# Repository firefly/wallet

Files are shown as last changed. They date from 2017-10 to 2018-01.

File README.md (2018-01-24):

Firefly Wallet
==============

Weclome to the Firefly DIY Air-gapped Hardware Wallet project.

There are still a few things we are working on, but we wanted to start
getting some files into the hands of eager developers.

Also, if you haven't seen it already, please check out our
[crowdsale](https://ethers.io/#!/app-link/contribute.firefly.city). By contributing
to the project, you get your very own yourNameHere.firefly.eth ENS name on the
Ethereum network and you help fund development of the Firefly.

Folders
-------

### Cases

Currently limited to 3D printable cases, but we would love to have other
creative people out there contribute interesting designs.

A better 3D printable case will be published soon, but for the impatient,
the prototype case is available.

### Diagrams

Images and source files used to build documentation. Currently we have a circuit schematic
and a breadboard layout for prototyping.

### Source

The Arduino sketch and required (modified) libraries.

Future
------

- Better 3D printed case; still being designed, but easier to wire (soonish)
- Printed Circuit Board (PCB) layout for more advanced, but tinier devices (future)

License
-------

MIT and BSD license. Each file includes license information at the top.

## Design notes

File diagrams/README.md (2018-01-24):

Diagrams
========

This folder will eventually get rolled into the documentation.

These files are still very experimental.

**Important:** The nRF24L01+ **MUST** be powered with the 3.3V; the 5V rail **WILL** destroy it.

Schematic
---------

The schematic here is a simple overview of the connections required between
the various components.

This schematic diagram can be opened and modified using [kicad](http://kicad-pcb.org).

Breadboard
----------

The breadboard diagram is useful for quickly prototyping the Firefly wallet and
verify components are working coreectly.

The breadboard diagram can be opened and modified using [Fritzing](http://fritzing.org).

License
-------

All documents in here are licensed under the MIT license and the Creative
Commons CC-BY-4 license; whichever you are more comforatable with.

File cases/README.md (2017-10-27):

Cases
=====

Here is a list of cases.

We welcome any interesting additions; they do not need to be 3D printed; a How-To on
building a Firefly into an Altoids tin or other clever ideas are just as awesome.

Credit Card v0.1
----------------

This is the case used for the prototype in our [demo viedo](https://firefly.city/#demo).

It has several problems, which we are addressing in a new revision:

- No power switch
- Overly complicated routing of wires

If you are impatient, feel free to try it out. Otherwise, we highly recommend you wait
for the next version.

Credit Card v0.2
----------------

The changes we are working on:

- Orienting the Arduino Nano to be vertical to minimize wiring distances
- Adding a power slider/spinner
- Likely stacking the batteries

Coming soon.

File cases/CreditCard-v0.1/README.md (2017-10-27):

Credit Card V0.1
================

This is a very early prototype, and my first time using [SketchUp](http://www.sketchup.com).

This is the version seen in the [demo video](https://firefly.city/#demo).

A newer Credit Card V1 will be out soon:

- Shorter wire distances and easier wire routing
- Power switch

However, for a quick and simple case you can use **today**, so you can work
on the Firefly from a coffee shop, this is what we use.

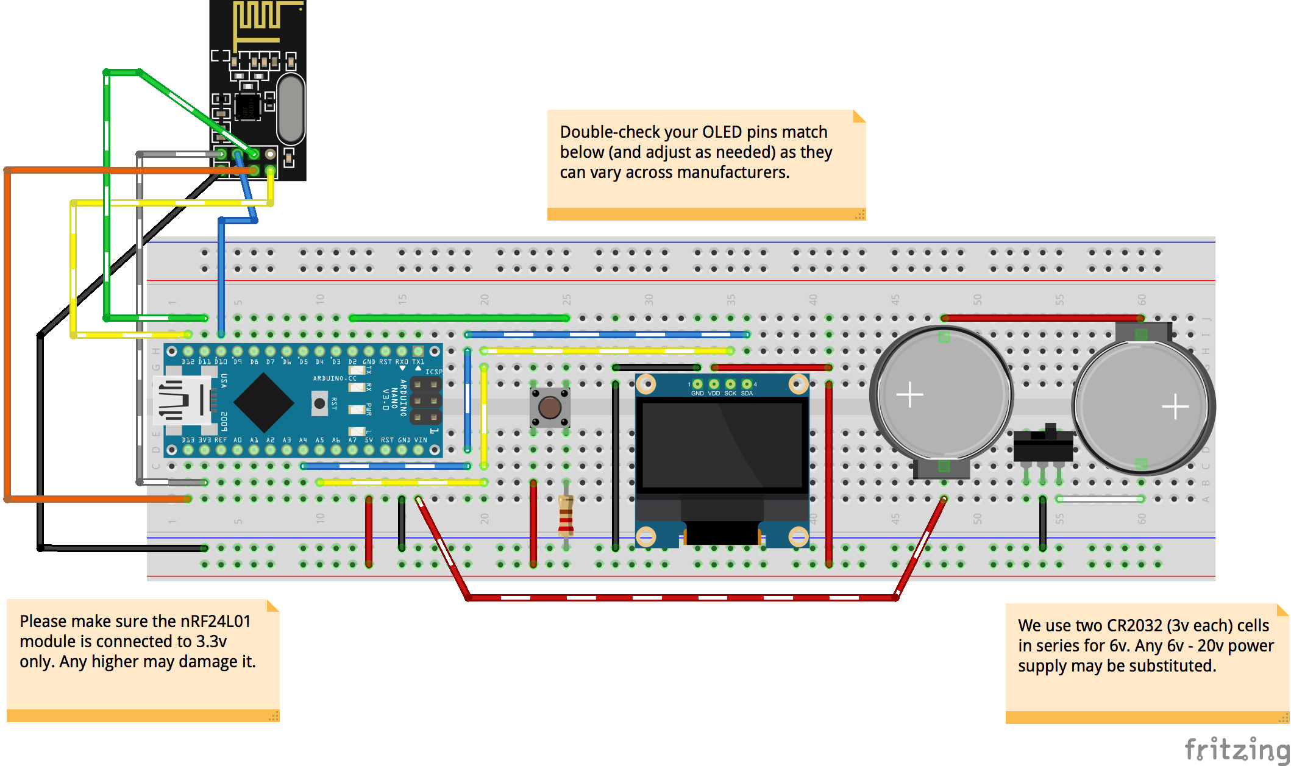
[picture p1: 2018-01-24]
diagrams/breadboard.png

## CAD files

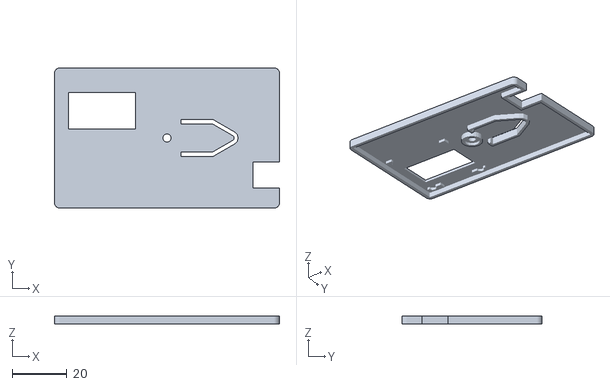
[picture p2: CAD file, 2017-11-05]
cases/CreditCard-v0.1/CreditCard-face.stl
82.5 x 51.5 x 3.00

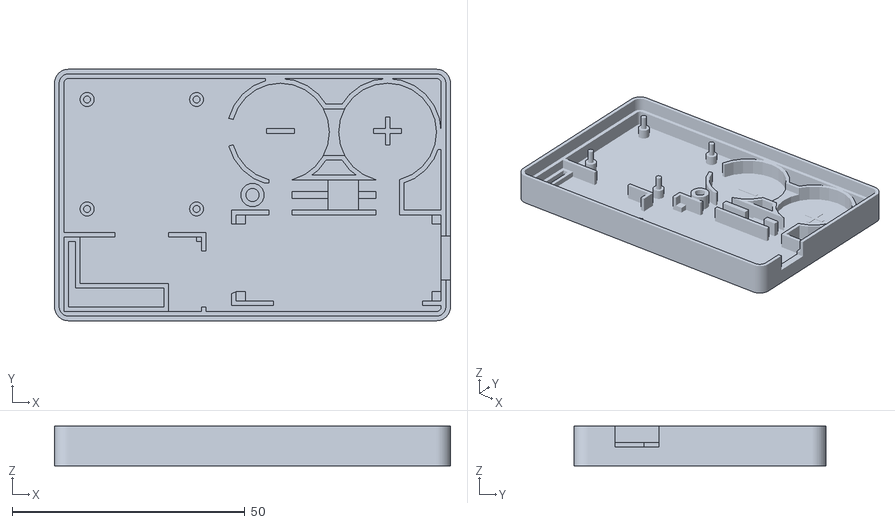
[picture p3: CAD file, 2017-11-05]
cases/CreditCard-v0.1/CreditCard-base.stl
85.0 x 54.0 x 8.50

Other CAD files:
cases/CreditCard-v0.1/CreditCard-base.dxf
cases/CreditCard-v0.1/CreditCard-face.dxf
cases/CreditCard-v0.1/credit-card.skp

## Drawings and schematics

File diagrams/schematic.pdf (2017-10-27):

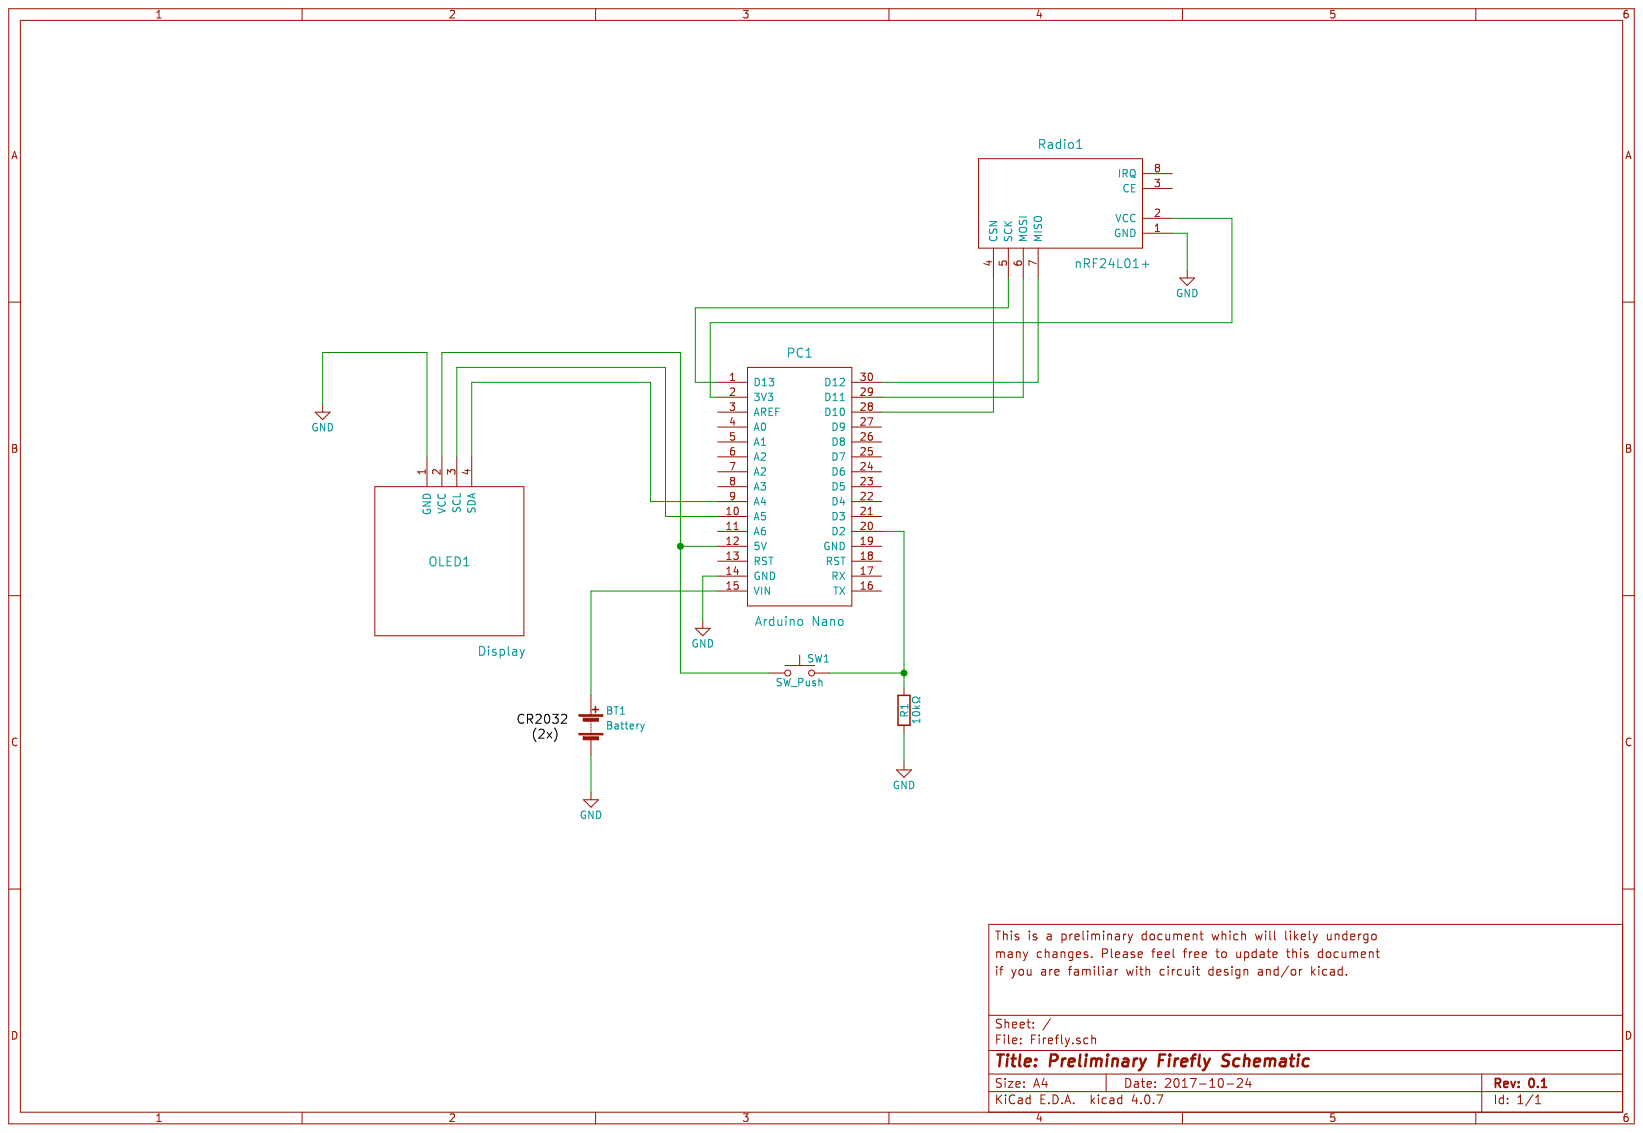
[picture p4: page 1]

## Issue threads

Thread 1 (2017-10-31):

Please add mesh of case

danfinlay, 2017-10-31:
I downloaded Sketchup, and tried exporting `.obj` files of the case, but when I do it, part of one of the sides seems to be non manifold, and so it's unprintable.

Could you also add some correctly meshed versions of the case, so they're ready to be 3D printed, without needing sketchup?

ricmoo, 2017-10-31:
Yes, I will upload one tonight. It should be a manifold, but I’ll debug that too.

I can upload a slic3r too.

danfinlay, 2017-10-31:
I think slicer gcode tends to be a little more printer-dependent, so really just a solid mesh is all I need. I have half of it printed fine (button half), just need the battery side.

(Can't wait to set it up!!)

ricmoo, 2017-11-04:
Sorry. DevCon has been more time consuming than I expected. I will try to get to this tonight.

danfinlay, 2017-11-04:
Sweet!

ricmoo, 2017-11-05:
I have added the STL files. Let me know if they don't work for you.

I need to upgrade my version of SketchUp to the Pro version before I can export the OBJ files.

danfinlay, 2017-11-05:
Looks good, thank you, printing now!

Closed 2017-11-05.

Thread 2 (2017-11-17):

Source code for the wallet is missing

slegge, 2017-11-17:
I bought a couple of the hardware wallet kits at ETHWaterloo and the instructions and source were supposed to be posted within days but they still aren't available.

ricmoo, 2017-11-18:
Sorry, it's been taking longer than expected to get the source code ready. On the plane back from DevCon on Wednesday we got RFC6979 working, which was one of the big bullet points we wanted finished before releasing. This means we don't need to rely on a RNG on device for signing, so it is much more secure.

My partner has also finished most of the testing platform so we can send/receive the test suite (same test suite as ethers.js) to the device over serial one test case at a time.

I am updating Ethers Wallet for iOS 11 and iPhone X right now, and then I will publish the branch with Firefly v0.1 support.

We are hoping to get the initial version of the source code up very soon, along with the new 3D printed case which is easier to wire up than the v0 currently posted.

maaft, 2017-12-14:
Any news regarding the source code? I'd love to jump in :)

ricmoo, 2018-01-24:
The source code is now up.

Thanks! :)

Closed 2018-01-24.

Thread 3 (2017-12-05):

Debouncing button to D2

martinsg88, 2017-12-05:
Just wanted to say I really like the project, very cool use of an arduino (or microcontroller in general).

Though if you would allow me, I have a question about your schematic. I see that you have a pull-down resistor to D2, however I am wondering what the input noise is like. It doesn't look like you are debouncing in hardware. Is this something you are solving in software? It seems like it would be more appropriate to add a 0.1uF capacitor as well?

ricmoo, 2017-12-06:
Sounds like you are far more an electronics person than I, especially in the analog circuits department.

Any suggestions you have would be greatly welcome, and I will research that.

For the Firefly, debouching shouldn't really be an issue since the button is at most ever pushed once, and the moment it gets a high signal, nothing else really matter, it never reads the button again.

martinsg88, 2018-01-25:
I deeply apologize for keeping this open this long.
Thanks again for the kind response.

Closed 2018-01-25.

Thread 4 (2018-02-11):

Schematic and Breadboard diagrams show that CE is not connected but it needs to be

tricdc, 2018-02-11:

ricmoo, 2018-02-11:
If CE is left floating, the nRF24L01+ will remain in receive mode. We could add a pull-up resistor to make sure, if it was a concern.

If we connect the CE pin to the Arduino, it will enable us to use certain power-saving stand-by modes, but also means the Firefly could theoretically broadcast.

By leaving it floating or using a pull up resistor, we ensure the chip is hard-wired into receive-only mode.

tricdc, 2018-02-11:
Oh, yeah sorry, i disconnected it yesterday and it wouldn't receive
transactions, but it works now

On Sun, Feb 11, 2018 at 1:43 AM, Richard Moore <notifications@github.com>
wrote:

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

Closed 2018-02-11.

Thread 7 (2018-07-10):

problem uploading onto arduino nano (Ubuntu18.04/Windows10)

crappybones, 2018-07-10:
Had this error message when I tried uploading the code via firefly.ino (this is from using the Ubuntu)
It looks to me theres an issue in the column size and also ive got to set a certain programmer?

Maybe theres a tutorial out there to help a noob like me

**************************************************************************************
Arduino: 1.8.5 (Linux), Board: "Arduino Nano, ATmega328P"

Build options changed, rebuilding all
/home/ubuntu/Arduino/libraries/firefly_blecast/src/aes-otfks-decrypt.c: In function 'aes_mix_columns':
/home/ubuntu/Arduino/libraries/firefly_blecast/src/aes-otfks-decrypt.c:321:9: warning: implicit declaration of function 'memset' [-Wimplicit-function-declaration]
         memset(temp_column, 0, AES_COLUMN_SIZE);
         ^
/home/ubuntu/Arduino/libraries/firefly_blecast/src/aes-otfks-decrypt.c:321:9: warning: incompatible implicit declaration of built-in function 'memset'
/home/ubuntu/Arduino/libraries/firefly_blecast/src/aes-otfks-decrypt.c:331:9: warning: implicit declaration of function 'memcpy' [-Wimplicit-function-declaration]
         memcpy(&p_block[i * AES_COLUMN_SIZE], temp_column, AES_COLUMN_SIZE);
         ^
/home/ubuntu/Arduino/libraries/firefly_blecast/src/aes-otfks-decrypt.c:331:9: warning: incompatible implicit declaration of built-in function 'memcpy'
/home/ubuntu/Arduino/libraries/firefly_blecast/src/aes-otfks-decrypt.c: In function 'aes_mix_columns_inv':
/home/ubuntu/Arduino/libraries/firefly_blecast/src/aes-otfks-decrypt.c:352:9: warning: incompatible implicit declaration of built-in function 'memset'
         memset(temp_column, 0, AES_COLUMN_SIZE);
         ^
/home/ubuntu/Arduino/libraries/firefly_blecast/src/aes-otfks-decrypt.c:364:9: warning: incompatible implicit declaration of built-in function 'memcpy'
         memcpy(&p_block[i * AES_COLUMN_SIZE], temp_column, AES_COLUMN_SIZE);
         ^
/home/ubuntu/Arduino/libraries/firefly_blecast/src/firefly_blecast.c: In function 'blecast_poll':
/home/ubuntu/Arduino/libraries/firefly_blecast/src/firefly_blecast.c:674:31: warning: initialization makes integer from pointer without a cast
         uint8_t whitenIndex = whitenMask + radio_getChannel(message) * 17;
                               ^
Sketch uses 28146 bytes (91%) of program storage space. Maximum is 30720 bytes.
Global variables use 383 bytes (18%) of dynamic memory, leaving 1665 bytes for local variables. Maximum is 2048 bytes.
avrdude: stk500_recv(): programmer is not responding
avrdude: stk500_getsync() attempt 1 of 10: not in sync: resp=0x00
avrdude: stk500_recv(): programmer is not responding
avrdude: stk500_getsync() attempt 2 of 10: not in sync: resp=0x00
avrdude: stk500_recv(): programmer is not responding
avrdude: stk500_getsync() attempt 3 of 10: not in sync: resp=0x00
avrdude: stk500_recv(): programmer is not responding
avrdude: stk500_getsync() attempt 4 of 10: not in sync: resp=0x00
avrdude: stk500_recv(): programmer is not responding
avrdude: stk500_getsync() attempt 5 of 10: not in sync: resp=0x00
avrdude: stk500_recv(): programmer is not responding
avrdude: stk500_getsync() attempt 6 of 10: not in sync: resp=0x00
avrdude: stk500_recv(): programmer is not responding
avrdude: stk500_getsync() attempt 7 of 10: not in sync: resp=0x00
avrdude: stk500_recv(): programmer is not responding
avrdude: stk500_getsync() attempt 8 of 10: not in sync: resp=0x00
avrdude: stk500_recv(): programmer is not responding
avrdude: stk500_getsync() attempt 9 of 10: not in sync: resp=0x00
avrdude: stk500_recv(): programmer is not responding
avrdude: stk500_getsync() attempt 10 of 10: not in sync: resp=0x00
Problem uploading to board.  See http://www.arduino.cc/en/Guide/Troubleshooting#upload for suggestions.

This report would have more information with
"Show verbose output during compilation"
option enabled in File -> Preferences.

ricmoo, 2018-07-10:
Those warnings look unrelated.

I’ve had that error before on macOS when the cable I was using was power-only (didn’t support data), so you may try changing the cable? Or check the driver.

Does the standard blink sketch load ok?

ricmoo, 2018-07-10:
(sorry; didn’t mean to close the issue, I tapped the wrong button)

JosefJ, 2018-10-02:
Setting up an old bootloader worked for me: `Tools > Processor > [...] (Old Bootloader)`

ricmoo, 2018-10-02:
Oh yes! Make sure the boot-loader matches your Arduino device.

The Firefly firmware works with either the "old boot loader" or the the new "Optiboot", but you must select in the IDE the one that matches your device.

jiangfuyao, 2019-03-27:
@ricmoo I have the same issue, change `arduino` use ATmega328 (Old Bootloader) some time OK, But in the `Fritzing` can't change to ATmega328 (Old Bootloader). so have same issue, can't check it on the Fritzing

ricmoo, 2019-03-27:
You mean you are trying to upload using Fritzing? I have not ever used software other than the Arduino IDE; I didn’t even know that Fritzing had uploading capabilities. Can you try the Arduino IDE instead?

jiangfuyao, 2019-03-27:
Fritzing's code view, upload to put the Simulator running.

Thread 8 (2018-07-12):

Different OLED screen

anarchy89, 2018-07-12:
Hi,

I accidentally bought the wrong Oled screen. I bought this one Monochrome 0.96" 128x64 OLED graphic display https://www.adafruit.com/product/326 instead.

I was wondering if there is any way to rewire it or change the source code to make it work with this screen instead.

ricmoo, 2018-07-12:
The SPI (what you have) and I2C (the one we use) version are both identical in terms of the controller, it is just the wiring that is different on the board. It would be quite the under-taking though to rewire the board.

You may also be able to run two SPI devices (the screen in the nRF24L01+) by changing the CSN to select which one, but I haven't had time to do that yet.

It is certainly possible to make it work, but is a very involved task, requiring either substantial effort on the hardware side, or non-trivial effort on the software side. :(

Don't have any short term solution for you though... If you want to add support for SPI screens though, we'd definitely like to add the support. :)

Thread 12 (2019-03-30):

iphoneX not compatible Firefly

jiangfuyao, 2019-03-30:
Use iphoneX click Authorize with Friefly Wallet button, the Firefly doesn't have echo.
But use iphone 6 plus, Firefly have echo: 0xca....09d2, 0.001, ok?

ricmoo, 2019-03-30:
Sorry, I don't understand.

I have uses my Firefly devices successfully with iPhone 6, iPhone 6s, iPhone 6 Plus, iPhone 7 and iPhoneX. Have you tried other transactions and amounts? I believe there was an early bug with specific messages.

The newer version of Firefly fixes this, and it will be available soon. If sending 1.0 ether does not work, try 1.01, for example. There was a problem with the computation of the recovery ID in certain situations.

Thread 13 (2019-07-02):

[Feature] Support Monero

David-Beetle, 2019-07-02:
**Feature**: Support Monero
**Why?**: Monero is an amazing privacy coin. Great for users who do not wallet their balance publicly available. Plenty of wallets written both in [C++](https://github.com/monero-project/monero) and [Rust](https://github.com/monero-rs)

_____________________

Want to support this issue? Post a bounty on it! We accept bounties via [BountySource](https://www.wikipedia.org/wiki/Bountysource).

[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]()

ricmoo, 2019-07-02:
I'm working on a brand new version of the Firefly with substantially more gusto.

However, the current Firefly in this repo uses BLECast, which cannot carry payloads large enough for UTXO-based coins. A great deal of thought must go into a lot of the low-level aspects on platforms which only have 2,048 bytes of RAM, so it is not easy to just add a coin. :)

David-Beetle, 2019-07-02:
@ricmoo I don't want to be rude, but would it be possible to run this on something like a beagle board black? It might be a bit thick (plus expensive), and probably won't be very easy to travel with, but it has up to 4 GB of RAM. Plus, unlike the PIs it only requires non-free software for VPU which can be done on the CPU

**Related Links**:
https://www.fsf.org/resources/hw/single-board-computers

alexeyneu, 2019-07-06:
it doesnt have 4gb . 1gb maximum
http://beagleboard.org/bone

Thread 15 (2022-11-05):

fatal error: asm_arm.inc: No such file or directory   185 |     #include "asm_arm.inc"

wighawag, 2022-11-05:
This is not really an issue with firefly, but I am exploring making a wallet on a different hardware and would like to reuse your ethers.c code

But when I try to compile ethers lib for this hardware : Allwinner V3s  (ARM Cortex A7-A)
I get the following error
```
 fatal error: asm_arm.inc: No such file or directory
  185 |     #include "asm_arm.inc"
```

any clue on what I should put in asm_arm.inc ?

ricmoo, 2022-11-05:
You may be able to just remove that and fallback onto the non-asm VLI operations.

Otherwise, check out micro-ecc and to grab the relevant file.

I’ll have a RISC-V implementation up soon too. I just got the new PCBs in the mail. :)

ricmoo, 2022-11-05:
(FYI: https://github.com/kmackay/micro-ecc)

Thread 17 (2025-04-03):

When sending a transaction, ethers wallet does not have the "Authorize with Firefly Wallet" button, only "Send Payment".

AmazingZ-sys, 2025-04-03:
my device is iPhone 13 pro

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

AmazingZ-sys, 2025-04-07:
I would really appreciate your help. I followed the code and circuit provided in the repository, but I wasn't able to reproduce the hardware wallet.

ricmoo, 2025-04-07:
This old version of the hardware wallet hasn’t been updated in quite some time. Not exactly sure what the problem could be, but if you would like to try out our new wallet, check out the [firefly pixie](https://github.com/firefly/pixie-device) (it’s in the same org on GitHub).

Message me@ricmoo.com and I can mail you a device too, if you want to start experimenting with it. ;)

AmazingZ-sys, 2025-04-07:
> This old version of the hardware wallet hasn’t been updated in quite some time. Not exactly sure what the problem could be, but if you would like to try out our new wallet, check out the [firefly pixie](https://github.com/firefly/pixie-device) (it’s in the same org on GitHub).
>
> Message [me@ricmoo.com](mailto:me@ricmoo.com) and I can mail you a device too, if you want to start experimenting with it. ;)

Thank you very much. I’m currently trying to replicate the older version of the hardware wallet. May I ask if you have tested the compatibility of the Ethers Wallet on iOS 18 and iPhone 13 Pro? I’ve tested two sets of Arduino Nano and NRF24L01+ modules, and both sending and receiving messages are functioning properly, so I suspect the issue might lie in the app’s compatibility. Would you be able to help me with this?

ricmoo, 2025-04-07:
I haven’t tested on any recent hardware or software. I would expect it to still work, because it mimics the standard of BLE advertising data in a way that would break a lot of existing technology if they stopped supporting it.

Keep in mind the original wallet used BLE advertising data to get a tx or message from the phone to the device, but the other direction was performed using the phone camera to scan QR codes in the device.

The 2.4GHz radios in the NRF24L01+ only had (I believe?) 29 bytes of available overhead that could be exploited, which I recall being 3 bytes too small for a “legitimate” advertising packet, but it was something that could still be read. And I know other companies also used the same chip in knock-off cheap BLE iBeacons.

It has been a while, and I don’t recall all the technical details specifically, but you should also try out the app “LightBlue” as it is an excellent debugging tools when reverse-engineering the BLE protocol. It will tell you at least if your hardware is broadcasting the advertisements.

The protocol basically rapidly changes its advertising packets to shuttle data along using a circular buffer which includes the chunk offset. So if a packet is missed it will be discovered on another run around the loop. Each packet is also encrypted with a checksum, to identify packets that belong to the protocol compare to random background packets. You just need to make sure those key fields are aligned on the device and phone and it should work…

But it will take some debugging to find the issue. :)

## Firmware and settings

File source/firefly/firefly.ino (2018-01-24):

/**
  * MIT License
 * 
 * Copyright (c) 2017 Richard Moore <me@ricmoo.com>
 * Copyright (c) 2017 Yuet Loo Wong <contact@yuetloo.com>
 *
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
 * THE SOFTWARE IS PROVIDED "AS IS", WITHOUT WARRANTY OF ANY KIND, EXPRESS OR
 * IMPLIED, INCLUDING BUT NOT LIMITED TO THE WARRANTIES OF MERCHANTABILITY,
 * FITNESS FOR A PARTICULAR PURPOSE AND NONINFRINGEMENT. IN NO EVENT SHALL THE
 * AUTHORS OR COPYRIGHT HOLDERS BE LIABLE FOR ANY CLAIM, DAMAGES OR OTHER
 * LIABILITY, WHETHER IN AN ACTION OF CONTRACT, TORT OR OTHERWISE, ARISING FROM,
 * OUT OF OR IN CONNECTION WITH THE SOFTWARE OR THE USE OR OTHER DEALINGS IN THE
 * SOFTWARE.
 */

 
/**
 *  High-Level Information
 *  
 *  Scope Using Functions
 *  
 *  We move a lot of memory allocation-heavy operations into functions to ensure
 *  the compiler correctly generates code that cleans up after itself and releaeses
 *  memory once is it no longer needed. We need every ounce of memory and storage
 *  we can get our hands on.
 *  
 *  
 *  Malloc vs stack
 *  
 *  Each instance of malloc/free vs using stack space has been carefully examined
 *  as assembly and comparing generated code. In some instances, the code is inlined
 *  resulting in smaller code (odd, but poke around in the obj-dump to see weird
 *  reasons why, such as how smallish (less than the number of registers) arrays get
 *  passed in as individual parameters.
 *  
 *  I suspect this will change over time, and once a newer version of the compiler
 *  is used, with better -Os support, we can move more of these to use the stack.
 *  
 *  
 *  Available Trade-offs
 *  
 *  As we add more features, we may need to slim down the Storage or SRAM, depending on
 *  what we are low on. Some features can trade one for the other and some features we
 *  may be able to cripple in subtle ways to gain the space we need. Here is a list of
 *  current options:
 *  
 *  - The QR code may have penalty scores removed and always choose mask 0; less
 *    standards compliant but gains 1318 bytes of storage.
 *  - Use uECC Optimiation level 1 (instead of 2); increases signing from 6s to 7.2s but
 *    gains 2168 bytes of storage.
 */



/**
 *  Library Includes
 *  
 *  Each of these includes are in the ../libs/ folder and should be added to your
 *  Arduino `libraries` folder via a symlink.
 *  
 *  e.g. ln -s /home/ricmoo/firefly/wallet/source/libs/ethers /home/ricmoo/Arduino/libraries/ethers
 */


/**
 *  Private Key
 *  
 *  KEEP THIS SECRET!
 *  
 *  Anyone with this private key can steal your ether and any other crypto-assets associated with it.
 *  
 *  This is hard-coded, unencrypted into the version 0 (v0) protocol, but in the future versions
 *  of this software will have much more clever ways to create and store your private key.
 *  
 *  To generate a new random private key, in the terminal type:
 * 
 *  /home/ethers> python -c 'import os; print ", ".join([ str(ord(c)) for c in bytes(os.urandom(32)) ])'
 *  
 */

static const uint8_t privateKey[] = {
#error You MUST generate a new private key and add it here, then remove this error line
};


// For debugging, we want to enable Serial dumping, but in the final product
// removing the Serial printing squeaks in a bit more room for larger transactions
// received over BLECast.
#define DEBUG_SERIAL  0


// The Ethereum library (signing, parsing transactions and cryptographic hashes)
#include <ethers.h>

// A customied version of my QR code library, to improve memory, flash and storage space as needed
#include <firefly_qrcode.h>

// A customized version of my BLECast library, to improve memory, flash and storage space as needed
// In the future this will also be used for its AES implementation for encrypted private keys
#include <firefly_blecast.h>

// Our custom zero-memory display driver
#include "firefly_display.h"

typedef enum ErrorCode {
    ErrorCodeNone           = 0,
    ErrorCodeOutOfMemory    = 31,
    ErrorCodeSigningError   = 41,
    ErrorCodeInvalidKey     = 42,
    ErrorCodeStorageFailed  = 51,
} ErrorCode;


// The keccak256(privateKey)
#define EEPROM_DATA_OFFSET_CHECKSUM            (0)
#define EEPROM_DATA_LENGTH_CHECKSUM            (32)

// The secret key (symmetric) used for phone to send encrypted messages
#define EEPROM_DATA_OFFSET_PAIR_SECRET         (EEPROM_DATA_OFFSET_CHECKSUM + EEPROM_DATA_LENGTH_CHECKSUM)
#define EEPROM_DATA_LENGTH_PAIR_SECRET         (16) 

// The address of the private key
#define EEPROM_DATA_OFFSET_ADDRESS             (EEPROM_DATA_OFFSET_PAIR_SECRET + EEPROM_DATA_LENGTH_PAIR_SECRET)
#define EEPROM_DATA_LENGTH_ADDRESS             (20)

// The wallet URI (checksummed address with "ethereum:" scheme)
#define EEPROM_DATA_OFFSET_ADDRESS_URI         (EEPROM_DATA_OFFSET_ADDRESS + EEPROM_DATA_LENGTH_ADDRESS)
#define EEPROM_DATA_LENGTH_ADDRESS_URI         (9 + ETHERS_CHECKSUM_ADDRESS_LENGTH)   


extern unsigned int __heap_start;
extern void *__brkval;

/*
 * The free list structure as maintained by the 
 * avr-libc memory allocation routines.
 */
struct __freelist {
  size_t sz;
  struct __freelist *nx;
};

/* The head of the free list structure */
extern struct __freelist *__flp;


/* Calculates the size of the free list */
int freeListSize() {
  struct __freelist* current;
  int total = 0;
  for (current = __flp; current; current = current->nx) {
    total += 2; /* Add two bytes for the memory block's header  */
    total += (int) current->sz;
  }
  return total;
}

int freeMemory() {
  int free_memory;
  if ((int)__brkval == 0) {
    free_memory = ((int)&free_memory) - ((int)&__heap_start);
  } else {
    free_memory = ((int)&free_memory) - ((int)__brkval);
    free_memory += freeListSize();
  }
  return free_memory;
}


/**
 *  Our Hardware Configuration
 */
 
#define BUTTON_PIN            (2)

// ATmega 328
#define RADIO_PIN_CE          (9)
#define RADIO_PIN_CSN         (10)

// ATmega 2560
//#define RADIO_PIN_CE          (40)
//#define RADIO_PIN_CSN         (53)

#define DISPLAY_ADDRESS       (0x3c)


// Dumps a buffer
static void dumpBuffer(uint8_t *buffer, uint16_t length) {
#if DEBUG_SERIAL == 1
    //Serial.print("0x");
    for(uint16_t i = 0; i < length; i++) {
        // Prefix single nibble with a "0"
        if (buffer[i] < 0x10) { Serial.print("0"); }
        Serial.print((uint8_t)(buffer[i]), HEX);
        Serial.print(' ');
    }
    Serial.println("");
#endif
}

void dumpFreeMemory() {
#if DEBUG_SERIAL == 1
    display_debug_char(DISPLAY_ADDRESS, 'M');
    display_debug_int(DISPLAY_ADDRESS, freeMemory());
    display_debug_char(DISPLAY_ADDRESS, 'H');
    display_debug_int(DISPLAY_ADDRESS, (uint32_t)(&__heap_start));
    display_debug_char(DISPLAY_ADDRESS, 'B');
    display_debug_int(DISPLAY_ADDRESS, (uint32_t)(&__brkval));
    waitForButton();
    display_clear(DISPLAY_ADDRESS);
#endif
}

static char getHexNibble(uint8_t value) {
    value &= 0x0f;
    if (value <= 9) { return '0' + value; }
    return 'A' + (value - 10);
}

// If something goes wrong, indicate the error code and halt
static void crash(ErrorCode errorCode, uint16_t lineNo) {
    if (errorCode != ErrorCodeNone) {
        display_invert(DISPLAY_ADDRESS, true);
        display_clear(DISPLAY_ADDRESS);
    
        display_debug_text(DISPLAY_ADDRESS, (const char*)"ERR");
        display_debug_int(DISPLAY_ADDRESS, errorCode);
        
        display_debug_char(DISPLAY_ADDRESS, 'L');
        display_debug_int(DISPLAY_ADDRESS, lineNo);
    }    
    
    while (1) { delay(0x7fffffff); }
}

const char addressURIPrefix[] PROGMEM = {
    'e', 't', 'h', 'e', 'r', 'e', 'u', 'm', ':'
};

const char messageHeaderPrefix[] PROGMEM = {
    0x19, 'E', 't', 'h', 'e', 'r', 'e', 'u', 'm', ' ', 'S', 'i', 'g', 'n', 'e', 'd', ' ', 'M', 'e', 's', 's', 'a', 'g', 'e', ':', '\n'
};

static bool equalsStorage(uint16_t offset, uint16_t length, uint8_t *buffer) {
    for (uint16_t i = 0; i < length; i++) {
        if (buffer[i] != eeprom_read_byte((uint8_t*)(offset + i))) {
            return false;
        }
    }
    return true;
}

static void readStorage(uint16_t offset, uint16_t length, uint8_t *buffer) {
    for (uint16_t i = 0; i < length; i++) {
        buffer[i] = eeprom_read_byte((uint8_t*)(offset + i));
    }
}

static void writeStorage(uint16_t offset, uint16_t length, uint8_t *buffer) {
    for (uint16_t i = 0; i < length; i++) {
        eeprom_write_byte((uint8_t*)(offset + i), buffer[i]);
    }
    
    delay(100);
    
    // Make sure the data was written correctly
    if (!equalsStorage(offset, length, buffer)) {
        crash(ErrorCodeStorageFailed, __LINE__);
    }
}

static void generateCache() {
    uint8_t checksum[32];
    ethers_keccak256(privateKey, 32, checksum);
    
    // Already generated all the cached data (note: this is written last like a journal commit)
    if (equalsStorage(EEPROM_DATA_OFFSET_CHECKSUM, EEPROM_DATA_LENGTH_CHECKSUM, checksum)) {
        return;
    }

     // The largest amount of memory we need for anything we cache
    uint8_t scratch[9 + ETHERS_CHECKSUM_ADDRESS_LENGTH];

    // *********
    // Compute the address (leave some space at the beginning for the URI scheme in the next part)
    bool success = ethers_privateKeyToAddress(privateKey, &scratch[9]);
    if (!success) { crash(ErrorCodeInvalidKey, __LINE__); }
    writeStorage(EEPROM_DATA_OFFSET_ADDRESS, EEPROM_DATA_LENGTH_ADDRESS, &scratch[9]);

    // *********
    // Generate the wallet URI ("ethereum:" + checksumAddress);
    memcpy_P(scratch, addressURIPrefix, 9);

    // Place the null-terminated, checksum address into the string after the "ethereum:"
    ethers_addressToChecksumAddress(&scratch[9], (char*)&scratch[9]);

    writeStorage(EEPROM_DATA_OFFSET_ADDRESS_URI, EEPROM_DATA_LENGTH_ADDRESS_URI, scratch);

    // *********
    // Compute the pairing secret keccak(0x00 || keccak(privateKey))[:16]
    ethers_keccak256(checksum, 32, &scratch[33]);
    scratch[32] = 0;
    ethers_keccak256(&scratch[32], 33, scratch);
    
    writeStorage(EEPROM_DATA_OFFSET_PAIR_SECRET, EEPROM_DATA_LENGTH_PAIR_SECRET, scratch);

    // *********
    // Compute the pairing secret keccak(0x00 || keccak(privateKey))[:16]
    writeStorage(EEPROM_DATA_OFFSET_CHECKSUM, EEPROM_DATA_LENGTH_CHECKSUM, checksum);
}

static void showAddress() {

    // We use this scratch space for (QR Code module data) ("ethereum:" + checkSumAddress)
    uint8_t qrCodeBufferSize = qrcode_getBufferSize(3);
    uint8_t *scratch = (uint8_t*)malloc(qrCodeBufferSize + (9 + ETHERS_CHECKSUM_ADDRESS_LENGTH));

    // Load the cached URI from EEPROM
    readStorage(EEPROM_DATA_OFFSET_ADDRESS_URI, EEPROM_DATA_LENGTH_ADDRESS_URI, &scratch[qrCodeBufferSize]);

    QRCode qrcode;
    qrcode_initText(&qrcode, &scratch[0], 3, 0, (char*)(&scratch[qrCodeBufferSize]));
    display_qrcodes(DISPLAY_ADDRESS, &qrcode, NULL);

    free(scratch);
}

static void expandHexNibbles(uint8_t *buffer, uint8_t length) {
    for (int8_t i = length - 1; i >= 0; i--) {
        buffer[2 * i + 1] = getHexNibble(buffer[i]);
        buffer[2 * i + 0] = getHexNibble(buffer[i] >> 4);
    }
}

static void showPairingScreen() {
    // We use this scratch space for (QR Code Address) (temporary space to generate string)
    uint8_t qrCodeBufferSize = qrcode_getBufferSize(3);
    uint8_t *scratch = (uint8_t*)malloc(qrCodeBufferSize + 77);

    uint8_t *pairString = (&scratch[qrCodeBufferSize]);
    pairString[0] = 'V';
    pairString[1] = '0';
    pairString[2] = '/';
    pairString[43] = '/';
    pairString[76] = 0;

    // Put the raw binary in the pairing string and expand it into nibbles
    readStorage(EEPROM_DATA_OFFSET_ADDRESS, EEPROM_DATA_LENGTH_ADDRESS, &pairString[3]);
    expandHexNibbles(&pairString[3], 20);

    // Put the secret key (for transmission) in the pairing string and expand it into nibbles
    readStorage(EEPROM_DATA_OFFSET_PAIR_SECRET, EEPROM_DATA_LENGTH_PAIR_SECRET, &pairString[44]);
    expandHexNibbles(&pairString[44], 16);

    // Show the QR code
    QRCode qrcode;
    qrcode_initText(&qrcode, &scratch[0], 3, 0, (char*)pairString);
    display_qrcodes(DISPLAY_ADDRESS, &qrcode, NULL);

    free(scratch);
}

#define SHOW_PAIRIING_SCREEN_DURATION      3000

// Note: Messages over BLECase are sent as 16 byte chunks, where each chunk contains a 4 byte
//       preamble (3 bytes checksum, 1 bit END_FLAG, 1 bit PARTIAL_FLAG, 6 bits chunk index).
//       Blocks are repeated continuously since the protocol is one-directional, there is no
//       way for the sender to know a chunk has been received. The total message from the
//       driver is a 1 byte command followed by the payload
//
//       Command 0: The payload (up to 779 bytes) is an unsigned Ethereum transacrtion
//       Command 1: The payload (up to 128 bytes) is a printable-ASCII (plus \n) message
//       Command 2: The payload (up to 48 bytes) is a binary message
//
//       The MSB of the command must be 0. A top bit of 1 may be used in the future to
//       indicate a multi-byte command

static void waitForTransaction(uint8_t unsignedTransactionHash[32]) {    

    BLECastMessage message;
    message.radioPinCE = RADIO_PIN_CE;
    message.radioPinCSN = RADIO_PIN_CSN;

#if DEBUG_SERIAL == 1
    // The Serial library takes up extra space (buffers, etc), so we cannot have as large a message
    const uint16_t messageDataSize = 256;
#else
    // 780 will hold 60 payloads (12 bytes data + 1 byte marker) for a total payload of 720 bytes
    const uint16_t messageDataSize = 780;
#endif

    // Allocate a buffer to receive the message (payload)
    uint8_t *messageData = (uint8_t*)(malloc(messageDataSize));
    if (!messageData) { crash(ErrorCodeOutOfMemory, __LINE__); }

    // The secret key to listen for; Anyone with this key can send transactions to your
    // Firefly when on and can listen to ransactions sent from your phone
    uint8_t pairSecret[EEPROM_DATA_LENGTH_PAIR_SECRET];
    readStorage(EEPROM_DATA_OFFSET_PAIR_SECRET, EEPROM_DATA_LENGTH_PAIR_SECRET, pairSecret);
    blecast_init(&message, pairSecret, messageData, messageDataSize);

    // We use this to track how long the button has been held down
    uint16_t buttonOn = 0;

    while (true) {

        // Long-hold Button? Trigger pairing screen
        if (digitalRead(BUTTON_PIN)) {
             if (buttonOn == 0) {
                 display_invert(DISPLAY_ADDRESS, true);
             } else if (buttonOn > (SHOW_PAIRIING_SCREEN_DURATION + 49) / 50) {
                 display_invert(DISPLAY_ADDRESS, false);
                 break;
             }
             
             buttonOn++;

             delay(50);
             continue;

        } else if (buttonOn) {
             display_invert(DISPLAY_ADDRESS, false);
             buttonOn = 0;
        }
          
        bool foundMessage = blecast_poll(&message);
        if (!foundMessage) { continue; }

        Transaction transaction;

        // Check if this message is a valid transaction
        bool isValidTransaction = false;
        if (message.data[0] == 0x00) {
            isValidTransaction = ethers_decodeTransaction(&transaction, &message.data[1], message.size - 1);
        }

        // Valid transaction!
        if (isValidTransaction) {
            
            // First compute the hash, so we can clobber the data portion of the transaction (to use as the value string)
            ethers_keccak256(&message.data[1], message.size - 1, unsignedTransactionHash);

            // Hijack the data space to convert the value into a base-10 string (show up to 5 decimal places)
            ethers_toString(transaction.value, transaction.valueLength, (18 - 5), (char*)transaction.data);
            
            display_transaction(DISPLAY_ADDRESS, &transaction, (char*)transaction.data);
            
            break;

        // Valid message for signing
        } else if ((message.data[0] == 0x01 && message.size <= (128 + 1)) || (message.data[0] == 0x02 && message.size <= (48 + 1))) {

            uint8_t *messageData = (&message.data[1]);
            uint8_t messageLength = message.size - 1;
            
            // Null terminate the message
            messageData[messageLength] = 0;

            display_message(DISPLAY_ADDRESS, (message.data[0] == 0x02), messageData, messageLength);

            // Move the data forward 32 bytes so we have room to inject the message header
            for (int8_t i = messageLength; i >= 0; i--) {
                messageData[i + 32] = messageData[i];
            }

            uint8_t offset = 32;

            // Prepend the length (in base 10, as ascii)
            if (messageLength == 0) {
                messageData[--offset] = '0';
                messageLength++;
            } else {
                uint8_t convertLength = messageLength;
                while (convertLength) {
                    messageData[--offset] = '0' + (convertLength % 10);
                    messageLength++;
                    convertLength /= 10;
                }
            }

            // Copy the message prefix 
            offset -= 26;
            memcpy_P(&messageData[offset], messageHeaderPrefix, 26);
            messageLength += 26;

            // Compute the hash of the string with the message prefix prepended
            ethers_keccak256(&messageData[offset], messageLength, unsignedTransactionHash);
                      
            break;
        }

        // Bad message; listen for another one
        blecast_reset(&message);
    }
    
    blecast_shutdown(&message);

    free(messageData);

    if (buttonOn) {
        showPairingScreen();
        crash(ErrorCodeNone, __LINE__);
    }
}


// Note: The URI is generated entirely using upper-case letters and symbols available
//       in the QR code standard for Alphanumeric types, so that everything fits in a
//       version 3 QR code (of 77 available characters, this uses 71)
static void generateSignatureURI(char component, uint8_t *signature, char *text) {
    // URI Scheme; i.e. "SIG:"
    text[0] = 'S';
    text[1] = 'I';
    text[2] = 'G';
    text[3] = ':';

    // URI path prefix; i.e. "(R|S)/"
    text[4] = component;
    text[5] = '/';

    // Null termination
    text[7 + 64 - 1] = 0;

    // URI path; i.e. "[0-9A-F]{64}"
    uint8_t offset = 6;
    for (uint8_t i = 0; i < 32; i++) {
        text[offset++] = getHexNibble(signature[i] >> 4);
        text[offset++] = getHexNibble(signature[i]);
    }
}


static void showSignedTransaction(uint8_t *signature) {
    uint8_t qrCodeBufferSize = qrcode_getBufferSize(3);

    // We use this scratch space for: (QR Code R) (QR Code S) (temporary space to generate string)
    uint8_t *scratch = (uint8_t*)malloc(2 * qrCodeBufferSize + (7 + 64));
    if (!scratch) { crash(ErrorCodeOutOfMemory, __LINE__); }
    
    char *text = (char*)(&scratch[2 * qrCodeBufferSize]);

    // SIG:R/XXXX
    generateSignatureURI('R', &signature[0], text);

    QRCode qrcodeR;
    qrcode_initText(&qrcodeR, &scratch[0], 3, 0, text);

    // SIG:S/XXXX
    generateSignatureURI('S', &signature[32], text);

    QRCode qrcodeS;
    qrcode_initText(&qrcodeS, &scratch[qrCodeBufferSize], 3, 0, text);

    display_qrcodes(DISPLAY_ADDRESS, &qrcodeR, &qrcodeS);

    free(scratch);
}


static void signAndShowTransaction(uint8_t *unsignedTransactionHash) {

    uint8_t signature[ETHERS_SIGNATURE_LENGTH];
    bool success = ethers_sign(privateKey, unsignedTransactionHash, signature);

    if (!success) { crash(ErrorCodeSigningError, __LINE__); }

    showSignedTransaction(signature);
}

static void waitForButton() {
    // Wait for the button down
    while (!digitalRead(BUTTON_PIN)) { delay(50); }
    
    // De-bounce
    delay(50);
    
    // wait for the button up
    while (digitalRead(BUTTON_PIN)) { delay(50); }
}

// Execution begins here
void setup() {
  
#if DEBUG_SERIAL == 1
    Serial.begin(115200);
    while (!Serial) { }
#endif

    // Make sure we have cached things that take a while to compute
    generateCache();

    // Disable all interrupts (we don't need them and makes verifying the code execution easier)
    //SREG |= (1 << 7);
    //SREG &= ~(1 << 7);

    // Initialize the I2C OLED display
    display_init(DISPLAY_ADDRESS);

    // Show the wallet address
    showAddress();

    // Wait for a valid transaction over BLECast and compute its hash
    uint8_t unsignedTransactionHash[ETHERS_KECCAK256_LENGTH];
    waitForTransaction(unsignedTransactionHash);

    // Wait for the user to accept the transaction
    waitForButton();

    // Show the hour-glass waiting screen
    display_hourglass(DISPLAY_ADDRESS);

    // Sign the transaction and show the QR codes once read
    signAndShowTransaction(unsignedTransactionHash);

    // Done; spin forever and dream of turtles
    crash(ErrorCodeNone, __LINE__);
}


void loop() {
    // Never entered
}

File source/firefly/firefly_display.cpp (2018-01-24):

/**
 * MIT License
 * 
 * Copyright (c) 2017 Richard Moore <me@ricmoo.com>
 * Copyright (c) 2017 Yuet Loo Wong <contact@yuetloo.com>
 *
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
 * THE SOFTWARE IS PROVIDED "AS IS", WITHOUT WARRANTY OF ANY KIND, EXPRESS OR
 * IMPLIED, INCLUDING BUT NOT LIMITED TO THE WARRANTIES OF MERCHANTABILITY,
 * FITNESS FOR A PARTICULAR PURPOSE AND NONINFRINGEMENT. IN NO EVENT SHALL THE
 * AUTHORS OR COPYRIGHT HOLDERS BE LIABLE FOR ANY CLAIM, DAMAGES OR OTHER
 * LIABILITY, WHETHER IN AN ACTION OF CONTRACT, TORT OR OTHERWISE, ARISING FROM,
 * OUT OF OR IN CONNECTION WITH THE SOFTWARE OR THE USE OR OTHER DEALINGS IN THE
 * SOFTWARE.
 */
 

// See:
// http://www.ermicro.com/blog/?p=744
// http://playground.arduino.cc/Code/ATMELTWI


#include "firefly_display.h"

// Constants for I2C (see: http://www.atmel.com/webdoc/AVRLibcReferenceManual/group__util__twi.html)
#include <util/twi.h>

// Font Data
#include "firefly_fonts.h"

// Add attributes (i.e. packed) to an enum
// https://stackoverflow.com/questions/2791739/c-packing-a-typedef-enum
#ifdef __GNUC__
#define attribute(x) __attribute__((x));
#else
#define attribute(x)
#endif


// We use this to make sure the packing worked
// https://www.pixelbeat.org/programming/gcc/static_assert.html
#define ASSERT_CONCAT_(a, b) a##b
#define ASSERT_CONCAT(a, b) ASSERT_CONCAT_(a, b)
/* These can't be used after statements in c89. */
#ifdef __COUNTER__
  #define STATIC_ASSERT(e,m) \
    ;enum { ASSERT_CONCAT(static_assert_, __COUNTER__) = 1/(int)(!!(e)) }
#else
  /* This can't be used twice on the same line so ensure if using in headers
   * that the headers are not included twice (by wrapping in #ifndef...#endif)
   * Note it doesn't cause an issue when used on same line of separate modules
   * compiled with gcc -combine -fwhole-program.  */
  #define STATIC_ASSERT(e,m) \
    ;enum { ASSERT_CONCAT(assert_line_, __LINE__) = 1/(int)(!!(e)) }
#endif

// SSD1306 Command Codes
// See: https://cdn-shop.adafruit.com/datasheets/SSD1306.pdf
enum DisplayCommand {

    // Set Contrast  Control (1 byte operand follows)
    DisplayCommandSetContrast             = 0x81,        // Reset: 0x7f
    
    // Set Entire Display On
    //DisplayCommandSetFollowsRAM         = 0xa4,        // Reset
    //DisplayCommandSetIgnoresRAM         = 0xa5,
    
    // Set Normal/Inverse Display
    DisplayCommandSetNormal               = 0xa6,        // Reset
    DisplayCommandSetInvert               = 0xa7,

    // Set Display On/Off
    DisplayCommandOff                     = 0xae,        // Reset
    DisplayCommandOn                      = 0xaf,
    
    // Set memory address mode (1 byte operand follows; see below)
    DisplayCommandMemoryAddressMode               = 0x20,
    DisplayCommandMemoryAddressModeHorizontal     = 0x00,
    DisplayCommandMemoryAddressModeVertical       = 0x01,    
    DisplayCommandMemoryAddressModePage           = 0x02,       // Reset

    // Set Column Address (3 byte operation follows; start and end; Reset: 0-127)
    DisplayCommandSetColumnAddress                = 0x21,
    
    // Set Page Address (3 byte operation follows; start and end; Reset: 0-7)
    DisplayCommandSetPageAddress                  = 0x22,

    // Set Segment Re-map
    DisplayCommandSegmentRemapNone            = 0xa0,    // Reset
    DisplayCommandSegmentRemap                = 0xa1,

    // Set COM Output Scan Direction
    DisplayCommandCOMScanIncrement            = 0xc0,    // Reset
    DisplayCommandCOMScanDecrement            = 0xc8,

    // Set Charge Pump Settings (See SSD1306 Application Notes; Section 2.1)
    // NOTE: A DisplayCommandOn (0xaf) must be issued afterward to activate
    DisplayCommandSetChargePump               = 0x8d,
    DisplayCommandSetChargePumpDisabled       = 0x10,    // Reset
    DisplayCommandSetChargePumpEnabled        = 0x14,

    // Set Pre-charge Period (1 byte operand follows; Reset 0x22)
    // A[3:0] - Phase 1 period of up to 15 DCLK clocks; 0 is invalid
    // A[7:4] - Phase 2 period of up to 15 DCLK clocks; 0 is invalid
    DisplayCommandSetPrechargePeriod          = 0xd9,

    // Set the V_COMH Deselecty Level (1 byte follows; Reset: 0x20)
    // A[6:4] - 0x00 = 0.65 x Vcc; 0x20 = 0.77 x Vcc ; 0x30 = 0.83 x Vcc 
    DisplayCommandSetVCOMHDeselectLevel       = 0xdb,

} attribute(packed);
typedef enum DisplayCommand DisplayCommand;

STATIC_ASSERT( sizeof ( DisplayCommand ) == 1, "DisplayCommand is incorrect width");


// Display Context
typedef struct DisplayContext {
    // We need 16 bytes per page + the 0x40 control byte per chunk
    uint8_t buffer[17];
    uint8_t length;
    uint8_t address;
} DisplayContext;


typedef enum ControlType {
    ControlTypeStart,
    ControlTypeData,
    ControlTypeStop,
} ControlType;

// We are trying a higher I2C frequency of 400kHz; if this is a bugging out your display, 100kHz is safe
#define F_I2C 400000L


static void i2c_init(DisplayContext *context) {
    
    // Enable the I2C bus on the chip pins
    digitalWrite(SDA, 1);
    digitalWrite(SCL, 1);

    // Set Pre-Scalar bits in the Status register and the Bit-Rate generator
    TWSR &= ~(TWPS0 | TWPS1);
    TWBR = ((F_CPU / F_I2C) - 16) / 2;

    TWCR = _BV(TWEN) | _BV(TWIE) | _BV(TWEA);

    // Set the address
    TWAR = (context->address << 1);
}


static uint8_t i2c_setControl(ControlType controlType) {
    switch(controlType) {
        case ControlTypeStart:
            TWCR = (1 << TWINT) | (1 << TWSTA) | (1 << TWEN);
            break;
        case ControlTypeData:
            TWCR = (1 << TWINT) | (1 << TWEN);
            break;
        case ControlTypeStop:
            TWCR = (1 << TWINT) | (1 << TWEN) | (1 << TWSTO);
            // Stop does not wait 
            return 0;
    }
    
    while (!(TWCR & (1 << TWINT)));

    // Mask out the prescaler and reserved bits
    return (TWSR & 0xF8);
}

static void i2c_begin(DisplayContext *context) {
    context->length = 0;
}

static void i2c_push(DisplayContext *context, uint8_t data) {
    context->buffer[context->length++] = data;
}

static void i2c_flush(DisplayContext *context) {
    uint8_t status;
 
    // Start
    status = i2c_setControl(ControlTypeStart);
    
    // i.e. status == TW_START

    // Set the slave for write
    TWDR = (context->address << 1) | TW_WRITE;
    i2c_setControl(ControlTypeData);

    // i.e. status == TW_MT_SLA_ACK
    
    // Write data
    for (uint8_t i = 0; i < context->length; i++) {
        TWDR = context->buffer[i];
        status = i2c_setControl(ControlTypeData);

        // i.e. status == TW_MT_DATA_ACK
    }

    // Stop
    status = i2c_setControl(ControlTypeStop);
    
    // i.e. status == 0 (returned explicitly in i2cSetControl)
    
    context->length = 0;
}

static void ssd1306_command(DisplayContext *context, uint8_t command) {
    i2c_begin(context);
    i2c_push(context, 0x00);
    i2c_push(context, command);
    i2c_flush(context);
}
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

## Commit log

2017-10-27 Adding first drafts of schematic and case.
    [Firefly.kicad_pcb, Firefly.sch, credit-card.skp]
2017-10-27 Moved case location.
    [credit-card.skp]
2017-11-05 Added STL files for Credit Card case v0.1.
    [CreditCard-base.stl, CreditCard-face.stl]
2018-01-24 Added breadboard layout.
    [Firefly.fzz]
2018-04-25 Added DXF files for the v0 case.
    [CreditCard-base.dxf, CreditCard-face.dxf]
